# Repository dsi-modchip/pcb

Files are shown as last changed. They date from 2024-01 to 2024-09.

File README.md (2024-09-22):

# DSi modchip PCB and flex-cable

> [!IMPORTANT]
> ***This PCB is still a work-in-progress and has bugs.***

This repository contains the KiCAD design files for the DSi modchip and the
cable flex-PCB.

## Notes

Currently, you'll have to order and make these yourself. I don't think making
them widely available already is a good idea, there's still a few bugs left in
the design.

The issues with the modchip PCB itself are listed [here](/wifi-interposer/TODO-r2.2.).
Additionally, inserting a cable into the modchips USB socket too forcefully can
cause the modchip PCB to snap in half, which is bad.

I haven't actually gotten the flex-cable to work properly. There are problems
with either a too large parasitic capacitance on the glitch signal line, or bad
contacts between the flexPCB and the glitching MOSFET. I suggest deadbugging
the crowbar MOSFET instead, if that's something you're capable of.

## Ordering/fab instructions

The modchip is a 4-layer board that should be 0.8 mm thick. I've gotten it
fabbed successfully from both Aisler (at 1.6mm thickness) and JLCPCB.

The flex-cable consists of two layers, needs stiffner in certain places, and
has been fabbed from JLCPCB.

## Bill of Materials

### Modchip main components

These are all the components required for the core functionality of the modchip.

| Reference | Value | Footprint | Qty | Farnell n° | LCSC n° | Mouser n° |
|:--- |:--- |:--- | ---:| ---:| ---:|:--- |
| C3,C4 | 27pF C0G | 0402 | 2 | 4539081 | C880615 | 603-CC402GRNPO9BN270 |
| C5,C6,C7,C10,C11,C12,C13,C14,C15,C16,C17 | 100nF | 0402 | 11 | 1758880 | C16772 | 791-0402B224K100CT |
| C8,C9 | 1uF | 0402 | 2 | 3013332 | C12530  | 187-CL05A105KP5NNNC |
| J1 | Molex SlimStack 501920-5001 | | 1 | N/A | N/A | 538-501920-5001 |
| J5 | Molex 200528-0040 | | 1 | 3500399 | N/A | 538-200528-0040 |
| Q4 | Dual NPMOS  | SOT-363/SC-70-6|1|3828400 | C155499 | 621-DMC3400SDW-13 |
| R1,R2 | 10k | 0402 | 2 | 2787800 | C25744  | 279-CRG0402J10K/10 |
| R5 | 47k | 0402 | 2 | 4004532 | C25792  | 279-CRG0402J47K |
| R7,R8 | 1k | 0402 | 2 | 4004531 | C11702  | 603-RC0402FR-131KL |
| SW1, SW2  | 1P1T button | 4.2x3.2mm | 2 | 3703693 | C2689510| 611-RKB2SJM250SMTRLF |
| U1 | RP2040 | QFN-56 P0.4 | 1 | 3766082 | C2040 | 358-SC09147 |
| U2,U4 | W25Q16JVUXIQ | DFN-8 P0.5mm |2| N/A | C2983691| 454-W25Q16JVUXIQTR |
| Y2 | 12 MHz 18pF | SMD3225 GND2/4 | 1 | 3572992 | C7424717| 774-403C35D12M00000 |

> [!NOTE]
> `J5` is optional, and is only needed when you use the flex-cable. It can be
> omitted when deadbugging the crowbar MOSFET.

> [!TIP]
> * For Q4, several compatible components exist: Diodes DMC{2710U,3400S,3401L}DW,
>   Toshiba SSM6L35FU.
> * For SW1 and SW2, you can use one of the following:
>   * C&K {RKB,PTS81[05]}2SJ[GKM]250SMTR LF
>   * Alps Alpine SKRPABE010
>   * E-Switch TL3365AF180QG
>   * CUI TS20-42-25-WT-160-SMT-TR
>   * Wurth 434123025826 or 434133025816
> * For U1, you could try using the RP2350A **once its erratum E9 has been
>   fixed in hardware**.
> * For U2 and U4, any similarly-sized 3.3V >100MHz QSPI flash chip should work.
>   Requirements on U4 are lower (only 1-bit SPI, 16 MHz) but it's often cheaper
>   to buy the same chip in bulk.
> * For Y2, try e.g. ECS-120-18-33 or ABM8(G)-12.000MHZ-18

### Modchip optional: USB connector

> [!IMPORTANT]
> You most likely want this, though *technically* everything can be done using
> an SWD debugger instead.

| Reference | Value | Footprint | Qty | Farnell n° | LCSC n° | Mouser n° |
|:--- |:--- |:--- | ---:| ---:| ---:|:--- |
| C1,C2 | 1uF | 0402 | 2 | 3013332 | C12530  | 187-CL05A105KP5NNNC |
| F1 | 0.5A | 0603 | 1 | 2850001 | C163116 | 530-C2Q500 |
| J3 | USBC 2.0 Recp | USBC 16P| 1 | 3819289 | C428463 | 640-USB4520031A |
| R3,R11 | 47k | 0402 | 2 | 4004532 | C25792  | 279-CRG0402J47K |
| R6,R12 | 5.1k | 0402 | 2 | 2447201 | C25905  | 708-RMCF0402FT5K10 |
| R9,R10 | 27 1% | 0402 | 2 | 4014781 | C100623 | 791-RMC1/16SK27R0FTH |
| U6 | AP2127K-3.3 | SOT-23-5  | 1 | 2510377 | C81233  | 998-MIC5504-3.3YM5TR |
| U3 | D1213A-02SM | SOT-23-5  | 1 | 3946109 | N/A | 621-D1213A-02SM-7 |
| U7 | USBLC6-2SC6 | SOT-23-6  | 1 | 1269406 | C2827654| 511-USBLC6-2SC6 |

> [!IMPORTANT]
> Use only one of `U3` or `U7`, never both!

### Modchip optional: LED

It indicates the status, except it doesn't work because there's no proper 5V
rail available when plugged into the DSi.

| Reference | Value | Footprint | Qty | Farnell n° | LCSC n° | Mouser n° |
|:--- |:--- |:--- | ---:| ---:| ---:|:--- |
| D1 | WS2812B | PLCC-2020 | 1 | N/A | C965555 | 485-4684  |
| R13 | 330 | 0402 | 1 | TODO | TODO | TODO |

### Modchip optional: WiFi module carrier

With a few extra components, you can make the modchip act as a real interposer
PCB between the DSi motherboard and the WiFi module.

| Reference | Value | Footprint | Qty | Farnell n° | LCSC n° | Mouser n° |
|:--- |:--- |:--- | ---:| ---:| ---:|:--- |
| C18,C19 | 1uF | 0402 | 2 | 3013332 | C12530  | 187-CL05A105KP5NNNC |
| J2 | Molex SlimStack 52991-0508 | | 1 | 3500613 | N/A | 538-52991-0508 |
| U5 | MIC5317-1.8YD5 | SOT-23-5 | 1 | 2809977 | C236669 | 998-MIC5504-1.8YM5TR |

> [!NOTE]
> Only short `JP1` if you intend to talk to the WiFi module in a standalone
> (i.e. non-interposer) manner.

> [!TIP]
> Instead of a MIC5317, many other SOT-23-5 LDOs such as the MIC5504-1.8YM5 can
> be used instead. I tend to pick ones with a low quiescent current. **Do pay
> attention to the pinout, though, as it sometimes changes even between
> SOT-23-5 parts of the same vendor.**

### Modchip optional: I2C level shifter

This can be a neat extra if you want to talk to the DSi's I2C bus. This was
used during modchip development, but isn't required at runtime.

| Reference | Value | Footprint | Qty | Farnell n° | LCSC n° | Mouser n° |
|:--- |:--- |:--- | ---:| ---:| ---:|:--- |
| C21 | 100nF | 0402 | 1 | 1758880 | C16772  | 791-0402B224K100CT |
| R4 | 200k | 0402 | 1 | 3537789 | C25764  | 791-WR04X2003FTL |
| U8 | PCA9306DC1  | VSSOP-8 | 1 | 2400482 | C33196  | 595-PCA9306DCUR |

> [!TIP]
> Instead of a PCA9306 (from either TI or NXP), an LSF0102 (from TI or
> Nexperia) or Nexperia NCA9306 can be used as well.

### Flex-cable

The flex-cable only needs a single IRFHS8342PbF as crowbar MOSFET. There's also
a footprint for a small 0402 series resistance at the gate (e.g. 200 Ohm), but
it can be shorted.

## Installing the modchip, flashing firmware and payload

See [the guide](https://github.com/dsi-modchip/guide?tab=readme-ov-file#dsi-modchip-guide).

## License

[CERN OHL-S v2](/LICENSE)

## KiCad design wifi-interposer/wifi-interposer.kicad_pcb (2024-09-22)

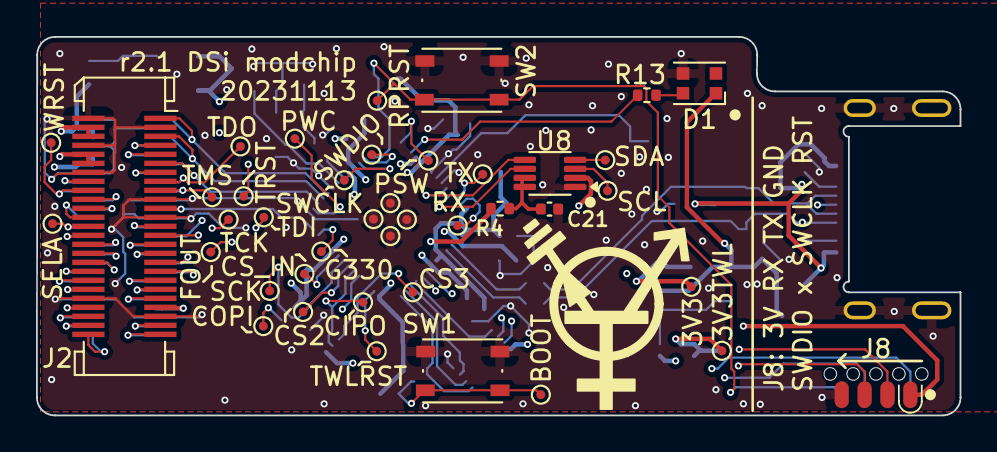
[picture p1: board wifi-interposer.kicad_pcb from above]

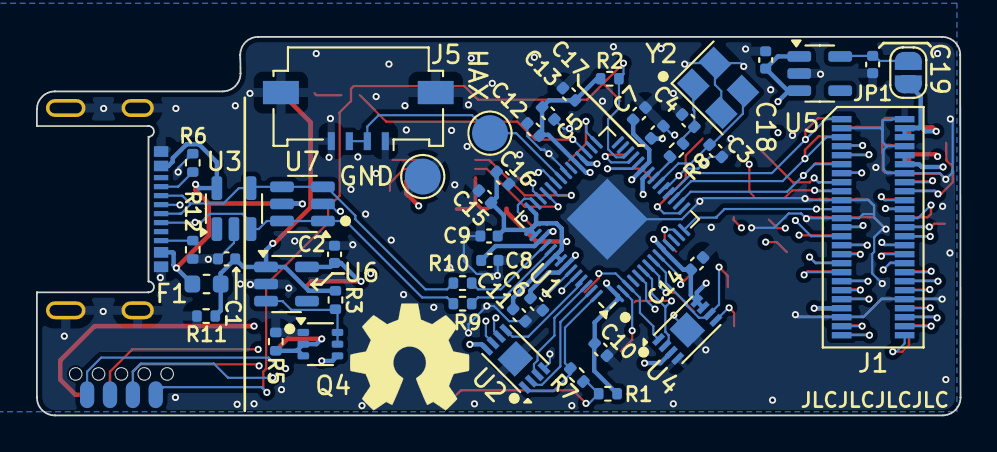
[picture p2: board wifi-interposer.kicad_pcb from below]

Board: 4 copper layers, 51.3 x 21.0 mm, 87 parts (46 on the bottom side), 81 nets.

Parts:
C1, C2, C8, C9, C18, C19: 1uF; C_0402_1005Metric
C3, C4: 27pF; C_0402_1005Metric
C5, C6, C7, C10, C11, C12, C13, C14, C15, C16, C17, C21: 100nF; C_0402_1005Metric
D1: WS2812B; LED_WS2812B-2020_PLCC4_2.0x2.0mm
F1: 0.5A; Fuse_0603_1608Metric
J1: TWL_WifiConn_Plug_TO_MAINBRD; Molex_SlimStack_501920-5001_2x25_P0.50mm_Vertical
J2: TWL_WifiConn_Rcpt_TO_WIFIBRD; Molex_SlimStack_52991-0508_2x25_P0.50mm_Vertical
J3: USB_C_Receptacle_USB2.0; USB_C_Receptacle_GCT_USB4510
J5: GlitchFPC; Molex_200528-0040_1x04-1MP_P1.00mm_Horizontal
J8: SOICbite; SOIC_clipProgSmall
JP1: SolderJumper_2_Open; SolderJumper-2_P1.3mm_Open_RoundedPad1.0x1.5mm
Q4: Q_Dual_NPMOS_S1G1D2S2G2D1; SOT-363_SC-70-6
R1, R2: 10k; R_0402_1005Metric
R3, R5, R11: 47k; R_0402_1005Metric
R4: 200k; R_0402_1005Metric
R6, R12: 5.1k; R_0402_1005Metric
R7, R8: 1k; R_0402_1005Metric
R9, R10: 27 1%; R_0402_1005Metric
R13: 330; R_0402_1005Metric
SW1, SW2: SW_Push; SW_Push_1P1T_NO_Vertical_Wuerth_434133025816
TP1: To glitch FET; TestPoint_Pad_D2.0mm
TP2: GND2 on CPU-TWL-01 PCB, TP14 on CPU-UTL-01 PCB; TestPoint_Pad_D2.0mm
TP3: SCK; TestPoint_Circular_D0.5
TP4: COPI; TestPoint_Circular_D0.5
TP5: CIPO; TestPoint_Circular_D0.5
TP6: CS_IN; TestPoint_Circular_D0.5
TP7: CS2; TestPoint_Circular_D0.5
TP8: CS3; TestPoint_Circular_D0.5
TP9: TDO; TestPoint_Circular_D0.5
TP10: TMS; TestPoint_Circular_D0.5
TP11: TDI; TestPoint_Circular_D0.5
TP12: TCK; TestPoint_Circular_D0.5
TP13: TRST; TestPoint_Circular_D0.5
TP14: FOUT; TestPoint_Circular_D0.5
TP15: SELA; TestPoint_Circular_D0.5
TP16: WRST; TestPoint_Circular_D0.5
TP17: TWLRST; TestPoint_Circular_D0.5
TP18: 3V3TWL; TestPoint_Circular_D0.5
TP19: 3V3; TestPoint_Circular_D0.5
TP20: RPRST; TestPoint_Circular_D0.5
TP21: BOOT; TestPoint_Circular_D0.5
TP22: TX; TestPoint_Circular_D0.5
TP23: RX; TestPoint_Circular_D0.5
TP24: SWCLK; TestPoint_Circular_D0.5
TP25: SWDIO; TestPoint_Circular_D0.5
TP29: SCL; TestPoint_Circular_D0.5
TP30: SDA; TestPoint_Circular_D0.5
TP32: G330; TestPoint_Circular_D0.5
TP33: PWC; TestPoint_Circular_D0.5
TP34, TP35, TP36, TP37: GND; TestPoint_Circular_D0.5
TP38: PSW; TestPoint_Circular_D0.5
U1: RP2040; QFN-56-1EP_7x7mm_P0.4mm_EP3.2x3.2mm
U2, U4: W25Q16JVUXIQ; DFN-8-1EP_3x2mm_P0.5mm_EP1.36x1.46mm
U3: D1213A-02SM; SOT-23-5
U5: MIC5317-1.8YD5; SOT-23-5
U6: AP2127K-3.3; SOT-23-5
U7: USBLC6-2SC6; SOT-23-6
U8: PCA9306DC1; VSSOP-8_2.3x2mm_P0.5mm
Y2: 12.000MHz; Crystal_SMD_3225-4Pin_3.2x2.5mm

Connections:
1V8_MBRD: J1.4 (VDD18), J1.6 (VDD18), J2.4 (VDD18), J2.6 (VDD18), JP1.2 (B), U8.2 (VREF1)
3V3_MBRD: J1.10 (VDD33), J1.12 (VDD33), Q4.2 (G), Q4.3 (D), R5.1, TP18.1, U1.32 (GPIO21)
+1V1: C6.2, C7.2, C8.2, U1.23 (DVDD), U1.45 (VREG_VOUT), U1.50 (DVDD)
+3V3: C2.1, C5.1, C9.1, C10.1, C11.1, C12.1, C13.1, C14.1, C15.1, C16.1, C17.2, C18.1, J2.10 (VDD33), J2.12 (VDD33), J8.1, Q4.4 (S), R1.1, R2.1, R4.2, TP19.1, U1.1 (IOVDD), U1.10 (IOVDD), U1.22 (IOVDD), U1.33 (IOVDD), U1.42 (IOVDD), U1.43 (ADC_AVDD), U1.44 (VREG_IN), U1.48 (USB_VDD), U1.49 (IOVDD), U2.8 (VCC), U4.3 (IO2), U4.7 (IO3), U4.8 (VCC), U5.1 (VIN), U5.3 (EN), U6.5 (VOUT)
+5V: F1.1, J3.A4 (VBUS), J3.A9 (VBUS), J3.B4 (VBUS), J3.B9 (VBUS), U3.5, U7.5 (VBUS)
/D+: R9.1, U1.47 (USB_DP)
/D-: R10.2, U1.46 (USB_DM)
/LED_WS2812: R13.2, U1.31 (GPIO20)
/QSPI_CLK: U1.52 (QSPI_SCLK), U2.6 (CLK)
/QSPI_SD0: U1.53 (QSPI_SD0), U2.5 (DI(IO0))
/QSPI_SD1: U1.55 (QSPI_SD1), U2.2 (DO(IO1))
/QSPI_SD2: U1.54 (QSPI_SD2), U2.3 (IO2)
/QSPI_SD3: U1.51 (QSPI_SD3), U2.7 (IO3)
/QSPI_~CS: R7.2, U1.56 (QSPI_SS), U2.1 (~CS)
/SCL33: U1.39 (GPIO27_ADC1), U8.6 (SCL2)
/SDA33: U1.38 (GPIO26_ADC0), U8.5 (SDA2)
/USB_D+: J3.A6 (D+), J3.B6 (D+), R9.2, U3.3, U7.1 (I/O1), U7.6 (I/O1)
/USB_D-: J3.A7 (D-), J3.B7 (D-), R10.1, U3.4, U7.3 (I/O2), U7.4 (I/O2)
/XIN: C3.2, U1.20 (XIN), Y2.3
/XOUT: C4.2, R8.1, Y2.1
/power/CC1: J3.A5 (CC1), R6.1
/power/CC2: J3.B5 (CC2), R12.1
/power/EN: Q4.5 (G), Q4.6 (D), R3.2, U6.3 (EN)
ATH_TX_H: J1.16 (ATH_TX_H), J2.16 (ATH_TX_H)
BBP_SCS: J1.35 (BBP_SCS), J2.35 (BBP_SCS)
BBP_SLEEP: J1.29 (BBP_SLEEP), J2.29 (BBP_SLEEP)
BB_RF_SCLK: J1.41 (BB_RF_SCLK), J2.41 (BB_RF_SCLK)
BB_RF_SDI: J1.39 (BB_RF_SDI), J2.39 (BB_RF_SDI)
BB_RF_SDO: J1.37 (BB_RF_SDO), J2.37 (BB_RF_SDO)
BTN_~BOOT: R1.2, R7.1, SW1.1, TP21.1
BTN_~RESET: J8.5, R2.2, SW2.1, TP20.1, U1.26 (RUN)
CCA: J1.36 (CCA), J2.36 (CCA)
FLASH_~WP: J1.28 (FLASH_~WP), J2.28 (FLASH_~WP)
GLITCH_OUT: J5.2, J5.3, TP1.1, U1.36 (GPIO24)
GND: C1.2, C2.2, C3.1, C4.1, C5.2, C6.1, C7.1, C8.1, C9.2, C10.2, C11.2, C12.2, C13.2, C14.2, C15.2, C16.2, C17.1, C18.2, C19.2, C21.2, D1.3 (VSS), J1.2 (GND), J1.3 (GND), J1.8 (GND), J1.14 (GND), J1.19 (GND), J1.23 (GND), J1.42 (GND), J1.45 (GND), J2.2 (GND), J2.3 (GND), J2.8 (GND), J2.14 (GND), J2.19 (GND), J2.23 (GND), J2.42 (GND), J2.45 (GND), J3.A1 (GND), J3.A12 (GND), J3.B1 (GND), J3.B12 (GND), J3.S1 (SHIELD), J5.1, J5.4, J5.MP (MountPin), J8.4, Q4.1 (S), R5.2, R6.2, R11.2, R12.2, SW1.2, SW2.2, TP2.1, TP34.1, TP35.1, TP36.1, TP37.1, U1.19 (TESTEN), U1.35 (GPIO23), U1.37 (GPIO25), U1.57 (GND), U2.4 (GND), U2.9 (EP), U3.2, U4.4 (GND), U4.9 (EP), U5.2 (GND), U6.2 (GND), U7.2 (GND), U8.1 (GND), Y2.2, Y2.4
GPIO330: TP32.1, U1.13 (GPIO10)
I2C_SCL: TP29.1, U8.3 (SCL1)
I2C_SDA: TP30.1, U8.4 (SDA1)
JTAG_TCK: J1.22 (JTAG_TCK), J2.22 (JTAG_TCK), TP12.1
JTAG_TDI: J1.20 (JTAG_TDI), J2.20 (JTAG_TDI), TP11.1
JTAG_TDO: J1.15 (JTAG_TDO), J2.15 (JTAG_TDO), TP9.1
JTAG_TMS: J1.17 (JTAG_TMS), J2.17 (JTAG_TMS), TP10.1
JTAG_~TRST: J1.24 (JTAG_~TRST), J2.24 (JTAG_~TRST), TP13.1
MCLK: J1.47 (MCLK), J2.47 (MCLK)
NC: J1.25 (NC), J2.25 (NC)
unnamed: D1.4 (DIN), R13.1
unnamed: C19.1, JP1.1 (A), U5.5 (VOUT)
unnamed: R8.2, U1.21 (XOUT)
unnamed: C21.1, R4.1, U8.7 (VREF2), U8.8 (EN)
P49: J1.49, J2.49
POWERCUT: TP33.1, U1.15 (GPIO12)
PWSW: TP38.1, U1.29 (GPIO18)
RESET: J1.50 (RESET), J2.50 (RESET), TP17.1, U1.2 (GPIO0)
RF_SCS: J1.33 (RF_SCS), J2.33 (RF_SCS)
RF_SLEEP: J1.31 (RF_SLEEP), J2.31 (RF_SLEEP)
RTC_FOUT: J1.21 (RTC_FOUT), J2.21 (RTC_FOUT), TP14.1, U1.14 (GPIO11)
SDIO_CLK: J1.1 (SDIO_CLK), J2.1 (SDIO_CLK), U1.18 (GPIO15)
SDIO_CMD: J1.11 (SDIO_CMD), J2.11 (SDIO_CMD), U1.16 (GPIO13)
SDIO_DAT0: J1.5 (SDIO_DAT0), J2.5 (SDIO_DAT0), U1.17 (GPIO14)
SDIO_DAT1: J1.9 (SDIO_DAT1), J2.9 (SDIO_DAT1)
SDIO_DAT2: J1.13 (SDIO_DAT2), J2.13 (SDIO_DAT2)
SDIO_DAT3: J1.7 (SDIO_DAT3), J2.7 (SDIO_DAT3)
SPI_CIPO: J1.32 (SPI_CIPO), J2.32 (SPI_CIPO), TP5.1, U1.6 (GPIO4), U4.2 (DO(IO1))
SPI_CLK: J1.30 (SPI_SCK), J2.30 (SPI_SCK), TP3.1, U1.8 (GPIO6), U4.6 (CLK)
SPI_COPI: J1.34 (SPI_COPI), J2.34 (SPI_COPI), TP4.1, U1.5 (GPIO3), U4.5 (DI(IO0))
SPI_~CS2: J2.27 (SPI_~CS2), TP7.1, U1.7 (GPIO5)
SPI_~CS3: TP8.1, U1.3 (GPIO1), U4.1 (~CS)
SPI_~CS_IN: J1.27 (SPI_~CS2), TP6.1, U1.9 (GPIO7)
SWCLK: J8.6, TP24.1, U1.24 (SWCLK)
SWDIO: J8.8, TP25.1, U1.25 (SWD)
TRCLK: J1.44 (TRCLK), J2.44 (TRCLK)
TRDATA: J1.40 (TRDATA), J2.40 (TRDATA)
TRRDY: J1.46 (TRRDY), J2.46 (TRRDY)
UART_RX: J8.2, TP23.1, U1.41 (GPIO29_ADC3)
UART_TX: J8.3, TP22.1, U1.40 (GPIO28_ADC2)
VBUS: C1.1, D1.1 (VDD), F1.2, R3.1, R11.1, U6.1 (VIN)
VDD18?: J1.43 (VDD18?), J2.43 (VDD18?)
WL_RXPE: J1.38 (WL_RXPE), J2.38 (WL_RXPE)
WL_TXPE: J1.48 (WL_TXPE), J2.48 (WL_TXPE)
~SEL_ATH: J1.26 (~SEL_ATH), J2.26 (~SEL_ATH), TP15.1
~WIFI_RST: J1.18 (~WIFI_RST), J2.18 (~WIFI_RST), TP16.1

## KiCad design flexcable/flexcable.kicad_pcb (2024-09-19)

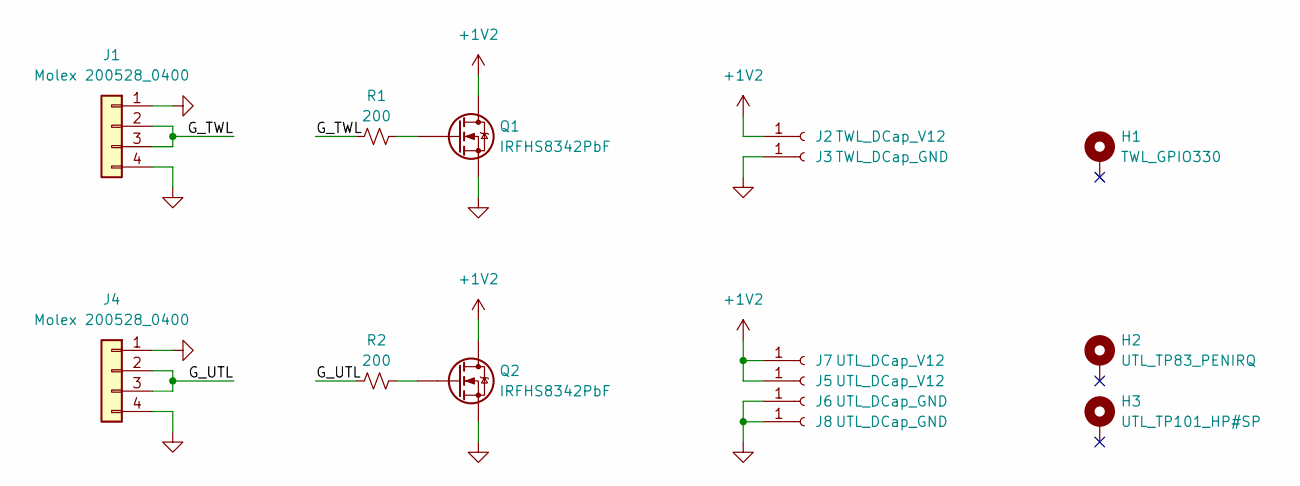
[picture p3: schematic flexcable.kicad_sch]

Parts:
H1: TWL_GPIO330; TestPointAnchor_D1.00
H2: UTL_TP83_PENIRQ; TestPointAnchor_D1.00
H3: UTL_TP101_HP#SP; TestPointAnchor_D1.00
J1, J4: Molex 200528_0400; Molex_2005280040_FPC
J2: TWL_DCap_V12; FPC_Castellated_Hole
J3: TWL_DCap_GND; FPC_Castellated_Hole
J5, J7: UTL_DCap_V12; FPC_Castellated_Hole
J6, J8: UTL_DCap_GND; FPC_Castellated_Hole
Q1, Q2: IRFHS8342PbF; PQFN6_2X2_INF
R1, R2: 200; R_0402_1005Metric

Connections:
+1V2: J2.1, J5.1, J7.1, Q1.1 (D), Q1.2 (D), Q1.5 (D), Q1.6 (D), Q1.7 (D), Q2.1 (D), Q2.2 (D), Q2.5 (D), Q2.6 (D), Q2.7 (D)
/G_TWL: J1.2, J1.3, R1.1
/G_UTL: J4.2, J4.3, R2.1
GND: J1.1, J1.4, J3.1, J4.1, J4.4, J6.1, J8.1, Q1.4 (S), Q1.8 (S), Q2.4 (S), Q2.8 (S)
unnamed: Q1.3 (G), R1.2
unnamed: Q2.3 (G), R2.2

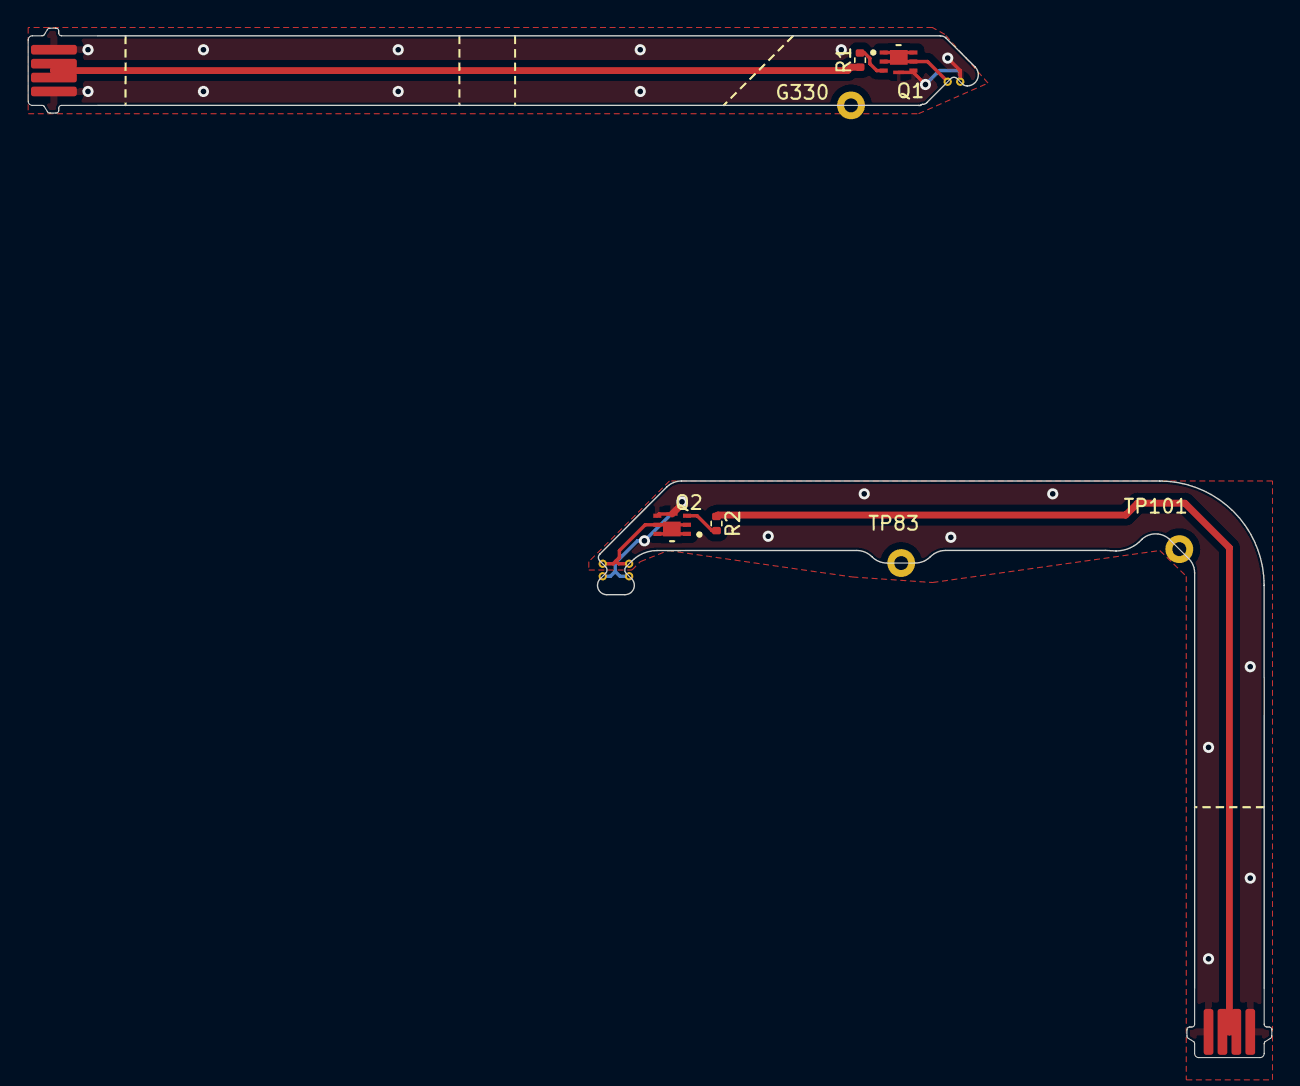
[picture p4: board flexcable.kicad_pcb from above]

Board: 2 copper layers, 89.4 x 74.0 mm, 15 parts (0 on the bottom side), 6 nets.

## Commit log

2024-01-05 initial (flexcable only)
    [flexcable.kicad_pcb, flexcable.kicad_sch]
2024-01-08 first fabable versions
    [flexcable.kicad_pcb, flexcable.kicad_sch, flexcable_fab.kicad_pcb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]
2024-01-09 push so that i can work on this on a desktop
    [flexcable.kicad_pcb]
2024-01-09 WIP moving stuff around to make it fit
    [flexcable.kicad_pcb, flexcable.kicad_sch]
2024-01-10 version ready-ish for fabrication
    [flexcable.kicad_pcb, flexcable_fab.kicad_pcb, flexcable_twl.kicad_pcb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]
2024-01-10 final tweaks (hopefully)
    [flexcable_fab.kicad_pcb]
2024-09-19 add wifi-interposer pcb design
    [flexcable.kicad_pcb, glitch_afe.kicad_sch, power.kicad_sch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]
2024-09-22 add README with BOM listing
    [power.kicad_sch, wifi-interposer.kicad_pcb, wifi-interposer.kicad_sch]
